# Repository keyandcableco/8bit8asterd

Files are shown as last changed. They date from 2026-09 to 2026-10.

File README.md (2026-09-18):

# 8b8 — 8-Bit 8asterd firmware

Arduino Leonardo driving three AY-3-8910A chips as a MIDI synth.

## Layout

- `8b8_firmware.ino` — the firmware
- `generate.py` — **single source of truth** for controllable parameters
- `parameters.h` — GENERATED. Do not edit by hand.
- `index.html` — GENERATED. Web Serial control panel (Chrome/Edge only).

## Workflow

Edit `PARAMS` / `PRESETS` in `generate.py`, then:

    python3 generate.py
    arduino-cli compile --fqbn arduino:avr:leonardo .
    arduino-cli upload -p /dev/ttyACM0 --fqbn arduino:avr:leonardo .

`generate.py` hashes the parameter definition into a layout-version byte.
When that byte changes the firmware ignores any saved EEPROM bank and boots
on defaults, so stale saves can never be misread as the new layout.

Open `index.html` directly in Chrome/Edge to control the unit. Close the tab
before flashing or the upload will fail on a busy serial port.

## Constraints

Leonardo (ATmega32u4): 28,672 bytes flash, 2,560 bytes RAM. RAM is the tight
one — keep constant tables in PROGMEM and read them with `pgm_read_*`.

Struct definitions must stay above the first function definition in the
.ino: the Arduino preprocessor inserts generated prototypes there, and a
type declared later breaks the build.

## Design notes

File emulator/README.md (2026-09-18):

# 8b8 emulator

Runs **the actual firmware** in a browser against three emulated AY-3-8910s.
`host.cpp` includes `8b8_firmware.ino` as a single translation unit, exactly
as the Arduino IDE builds it, so there is no second implementation to drift
out of step with the hardware.

The firmware needed one four-line change for this: an `AY_EMULATOR` seam in
`writeReg()` that hands register writes to the emulated chips instead of
bit-banging pins. It compiles to nothing on AVR.

## What's here

    arduino_shim.h   pins, PROGMEM, timers, EEPROM, Serial -- host stand-ins
    MIDIUSB.h        stub; the page injects note events into its queue
    MIDI.h           stub; DIN MIDI has no meaning in a browser
    ay8910.h         the chip: 3 tone channels, LFSR noise, envelope, log DAC
    host.cpp         drives setup()/loop(), renders audio, exposes the API
    emulator.html    GENERATED by ../generate.py -- same panel as index.html
    build-native.sh  g++ build for the tests
    build-wasm.sh    emcc build for the browser

## Build and run

    ./build-wasm.sh          # once emsdk is on your PATH
    python3 -m http.server 9111
    # open http://localhost:9111/emulator.html

Press **Start Audio**, then play with the letter keys (top rows pitched,
bottom row drums) or a MIDI keyboard.

## Tests

    ./build-native.sh && /tmp/8b8emu /tmp/out.wav

Renders a chord and a drum pattern to a WAV. `temper_test.cpp` reads the tone
periods the firmware programs and checks the temperaments land where they
should.

## Fidelity

The chip model steps at clock/8. The datasheet's tone frequency is
clock/(16*period) and the output toggles once per period, so a full square
cycle is two periods. Noise shifts every `2*period` steps and the envelope
advances every `32*period`, matching clock/(16*NP) and clock/(256*EP). The
DAC is the chip's logarithmic one, about 3dB per step.

Output is high-passed at about 3.5Hz to model the coupling capacitor on a
real board, so a muted channel's DC level does not appear as offset.

Not modelled: analogue output stage, supply noise, chip-to-chip variation,
and the exact bus timing (register writes go through the seam rather than
being decoded off BDIR/BC2).

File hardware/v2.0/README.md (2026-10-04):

# 8b8 hardware v2.0

RP2040 board for three YM2149 / AY-3-8910 sound chips, with eight analog
and eight switch inputs on terminal blocks. Everything except the sound chips
and the through-hole connectors is SMD with an LCSC part number, so JLC can
assemble it.

| File | What it is |
|---|---|
| `8b8_v2.kicad_pro`, `.kicad_sch`, `.kicad_pcb` | KiCad 9 project |
| `tools/design.py` | **The netlist, as data.** Every part, footprint, LCSC number and net. |
| `tools/gen_sch.py` | Writes the schematic from `design.py` |
| `tools/gen_pcb.py` | Writes the unrouted board: placement, outline, planes, silkscreen |
| `tools/route.py` | Autoroutes with Freerouting, then adds the copper pours |
| `tools/fixroute.py` | Small A* router for connections the autorouter left open |
| `tools/stitch.py` | Ground vias: beside stranded pads, a 4 mm grid, and inside walled-in pockets |
| `tools/cleanup.py` | Removes dangling track leftovers |
| `tools/check_netlist.py` | Checks that the schematic KiCad reads back matches `design.py` |
| `tools/check_pcb.py` | Checks every pad's net against the schematic, then runs DRC |
| `tools/fab.py` | Writes the JLC package into `fab/` |
| `fab/` | Gerbers (zip), BOM, CPL, and the list of through-hole parts |
| `renders/` | 3D views of the board |

## Status

Checked on the board as committed:

- **Schematic:** KiCad reads back the same 111 nets as `design.py`, with 0 mismatches.
  ERC shows 8 warnings, all one intended thing: the three chips' analog outputs
  are summed, as on v1.0. It's downgraded from error to warning in the project file.
- **Board:** 110 x 90 mm, 4 layers. **DRC: 0 errors, 0 unconnected, 0 schematic
  parity issues.** Every pad carries the right net. 6 cosmetic silkscreen
  warnings remain (a few labels touching vias); JLC clips silk off copper.
- **Stackup:** F.Cu signals, In1 solid GND, In2 signals plus +5V / +3V3 pours,
  B.Cu signals plus GND pour, ~350 stitching vias.
- **Rules:** 0.2 mm tracks, 0.15 mm clearance, 0.25 mm power, 0.6 / 0.3 mm vias.
  All standard JLC 4-layer capability.

### Before ordering

1. **Open it in KiCad and look.** It's autorouted. It's electrically complete
   and DRC-clean, but nobody has eyeballed it yet. Check the RP2040 and crystal
   area in particular, and tidy anything that looks odd.
2. **Check part rotations in JLC's CPL preview.** KiCad and JLC disagree on the
   zero rotation of some footprints (SOT-23, SOIC, the USB-C). JLC shows a
   preview after upload. Rotate any part whose pin 1 sits in the wrong corner.
3. **Through-hole parts** (sockets, terminal blocks) are in `fab/hand_solder.txt`.
   Add them as JLC through-hole assembly, or solder them yourself.
4. **Extended parts:** most ICs are JLC "Extended" library parts, so expect the
   per-part setup fee on top of the parts cost.

## Rebuilding

```bash
cd hardware/v2.0/tools
python3 gen_sch.py && python3 check_netlist.py
/usr/bin/python3 gen_pcb.py                        # needs KiCad's pcbnew module
DISPLAY=:0 /usr/bin/python3 route.py /path/to/freerouting-1.9.0.jar 15
DISPLAY=:0 /usr/bin/python3 route.py /path/to/freerouting-1.9.0.jar 8   # second pass
/usr/bin/python3 fixroute.py && /usr/bin/python3 stitch.py && /usr/bin/python3 stitch.py --islands
/usr/bin/python3 cleanup.py && /usr/bin/python3 check_pcb.py
/usr/bin/python3 fab.py
```

Freerouting 1.9 needs a display; it shows a window while it works. Autorouting
isn't deterministic, so a rebuild won't produce exactly this board. The last
few connections on this one were finished with a rip-up and reroute around
three debounce caps.

`gen_pcb.py` overwrites the board. **Now that it's routed, edit the layout by
hand in KiCad** and use *Update PCB from Schematic* for any circuit change. The
footprints are linked to the schematic symbols, so that works.

## What changed from v1

| | v1.0 (Pro Micro) | v2.0 |
|---|---|---|
| MCU | Pro Micro module on headers (ATmega32U4) | RP2040 on the board, 4 MB QSPI flash, 12 MHz crystal |
| Programming | Arduino bootloader | Hold BOOT, plug in USB, copy a `.uf2`. No programmer needed. |
| Logic to the chips | 5V straight from the 32U4 | Two 74HCT245 buffers (3.3V in, 5V out) |
| Warp Zone bends | A, B, X, Y (data bits DA1, DA0, DA5, DA4) on J3 | **Removed.** The firmware's Warp Zone does this safely. |
| CLK / RESET on J3 | `/SEL` (the half-clock bend) and `/RESET` | **Removed.** Clock Warp does the clock; reset is internal. |
| Inputs | none | 8 analog (74HC4051 to ADC0), 8 switch (74HC165) |
| Power | USB via Pro Micro | USB-C, 0.75 A polyfuse, AP2112K 3.3 V regulator |
| Audio out | 1k / 47n / 1u / 100k network | Same network, same values |
| MIDI in | 6N137, 220R, 1N4148 | Same circuit; output pulled up to 3.3 V |

## RP2040 pin map (for the firmware port)

| GPIO | Signal | Notes |
|---|---|---|
| 0-7 | DA0-DA7 | Data bus via U5. One masked write: `gpio_put_masked(0xFF, b)` |
| 8, 9 | BDIR_A, BC2_A | Chip A control via U6 |
| 10, 11 | BDIR_B, BC2_B | Chip B |
| 12, 13 | BDIR_C, BC2_C | Chip C |
| 14 | /RESET | All three chips. Pulled low until firmware drives it. |
| 15 | LED MIDI | Active high |
| 16 | spare | Test pad (UART0 TX, so a future MIDI out) |
| 17 | MIDI RX | UART0 RX, 31250 baud |
| 18, 19, 20 | MUX S0, S1, S2 | 74HC4051 channel select |
| 21 | CLOCK | GPOUT0. `clk_sys / 125` at 125 MHz gives exactly 1 MHz. Through U6, then 75R, then pin 22 of each chip. |
| 22, 23, 24 | SR /PL, CP, Q7 | 74HC165 |
| 25 | LED STATUS | Active high |
| 26 | MUX Z | ADC0 |
| 27, 28, 29 | spare | Test pads; ADC1-3 |

BC1 is grounded on every chip, the same reduced scheme as v1, so the
register-write sequence is unchanged.

Inside U5 and U6, channel *k* carries bit 7−*k*. That makes the bus run
straight from the RP2040 to the chips without crossing. It doesn't affect the
firmware: GPIO*n* still drives DA*n*.

### Reading the inputs

- **Analog:** set S2..S0 to the channel, wait about 10 µs, then read ADC0.
  Each input has 1k series and 10nF to ground. Pot ends go to the terminal's
  3V3 and GND pins, so the reading is ratiometric.
- **Switches:** pulse /PL low to latch, then clock out 8 bits on CP and read Q7.
  D0 (switch 1) comes out first. Inputs are active low: closed = 0. Each has
  a 10k pull-up and 1k/100nF debounce.

## Open questions

1. **v1.0 C2 is labelled "47uF" but drawn as a 5 mm disc ceramic.** v2.0 uses
   47 nF (3.4 kHz low-pass with the 1k). If your built v1 boards really have
   47 µF there, change it in `design.py`.
2. **v1.0 MIDI terminal labels.** v1's J3 labels the opto-cathode side "MIDI 4"
   and the 220R side "MIDI 5". The MIDI spec has DIN pin 4 on the resistor side,
   so v2.0 labels it that way. The circuit is identical; only the silkscreen
   differs.
3. **/A9, A8 and /SEL are left open, as on v1.0.** The chips pull them to the
   normal state. Tie them explicitly if you prefer.

## License

Copyright © 2026 Greg Miller / The Key & Cable Company.

The v2 hardware design files are licensed under the [CERN Open Hardware Licence Version 2 – Strongly Reciprocal (CERN-OHL-S-2.0)](../../LICENSE-HARDWARE). You can make, modify, sell and share hardware from them. If you share a modified design, or ship hardware made from one, you have to publish your design files under the same licence. The firmware is GPL-3.0 (see [LICENSE](../../LICENSE)).

Source location: <https://github.com/keyandcableco/8bit8asterd>

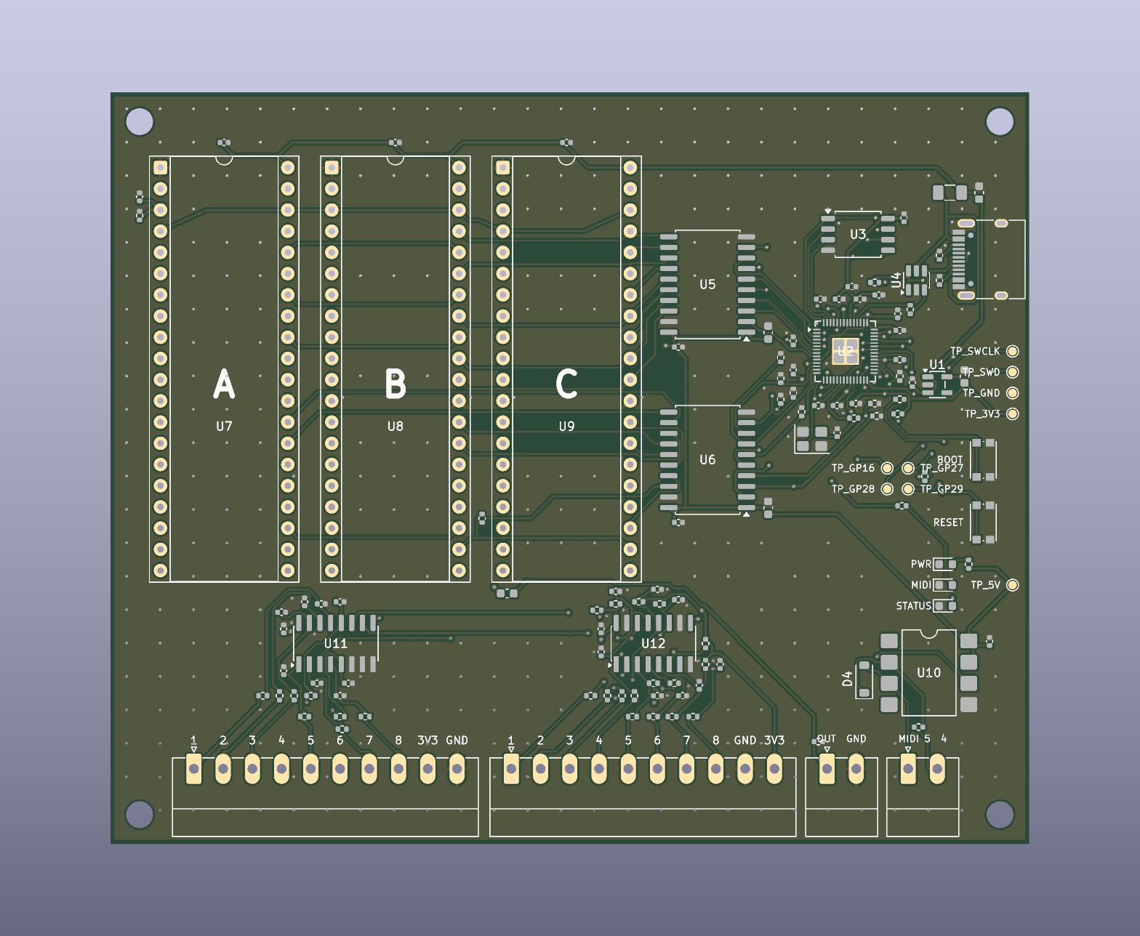
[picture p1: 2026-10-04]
hardware/v2.0/renders/8b8_v2_top.png

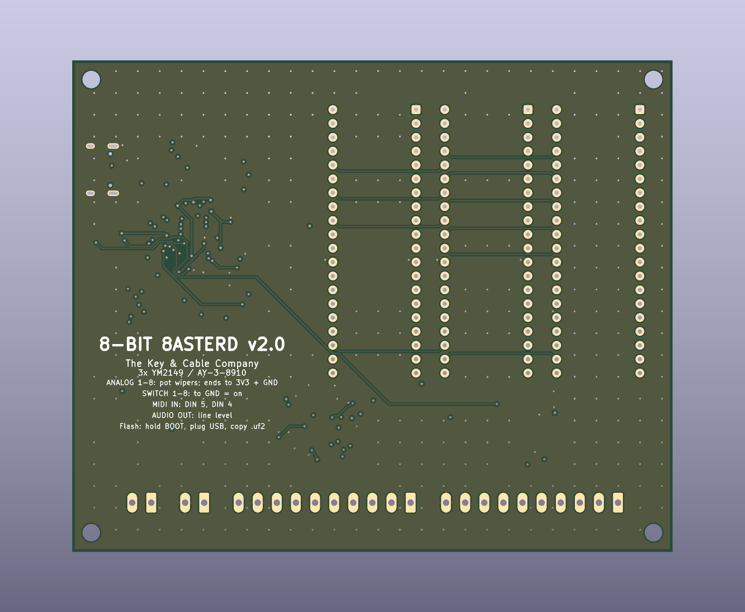
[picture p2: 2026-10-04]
hardware/v2.0/renders/8b8_v2_bottom.png

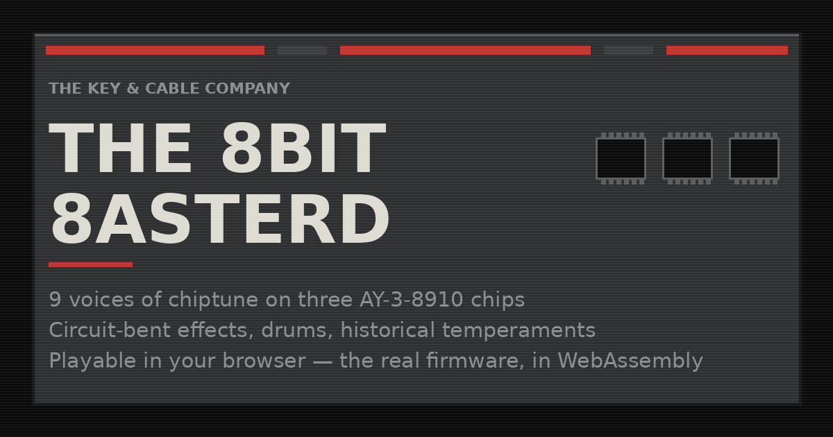
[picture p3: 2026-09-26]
emulator/social.png

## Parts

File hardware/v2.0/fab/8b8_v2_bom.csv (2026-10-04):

Comment | Designator | Footprint | LCSC Part #
10uF | C1,C2,C3 | C_0603_1608Metric | C96446
15pF | C18,C19 | C_0402_1005Metric | C1548
47nF | C26 | C_0402_1005Metric | C272875
1uF | C27 | C_0603_1608Metric | C106248
10nF | C30,C31,C32,C33,C34,C35,C36,C37 | C_0402_1005Metric | C15195
1uF | C4,C16,C17 | C_0402_1005Metric | C52923
10uF | C5 | C_0603_1608Metric | C19702
100nF | C6,C7,C8,C9,C10,C11,C12,C13,C14,C15,C20,C21,C22,C23,C24,C25,C28,C29,C38,C39,C40,C41,C42,C43,C44,C45,C46 | C_0402_1005Metric | C1525
PWR | D1 | LED_0603_1608Metric | C12624
MIDI | D2 | LED_0603_1608Metric | C12624
STATUS | D3 | LED_0603_1608Metric | C2286
1N4148W | D4 | D_SOD-123 | C81598
0.75A | F1 | Fuse_1206_3216Metric | C70078
USB-C | J1 | USB_C_Receptacle_HRO_TYPE-C-31-M-12 | C165948
5.1k | R1,R2 | R_0402_1005Metric | C25905
100k | R10,R11,R12,R13,R14,R15,R16,R17,R20 | R_0402_1005Metric | C25741
75 | R18 | R_0402_1005Metric | C25133
220 | R21 | R_0402_1005Metric | C25091
10k | R22,R32,R34,R36,R38,R40,R42,R44,R46 | R_0402_1005Metric | C25744
1k | R3,R4,R5,R8,R9,R19,R23,R24,R25,R26,R27,R28,R29,R30,R31,R33,R35,R37,R39,R41,R43,R45 | R_0402_1005Metric | C11702
27 | R6,R7 | R_0402_1005Metric | C25156
BOOT | SW1 | SW_Push_1P1T_NO_CK_KMR2 | C318884
RESET | SW2 | SW_Push_1P1T_NO_CK_KMR2 | C318884
AP2112K-3.3 | U1 | SOT-23-5 | C51118
6N137S | U10 | SMDIP-8_W9.53mm | C16496
74HC4051 | U11 | SOIC-16_3.9x9.9mm_P1.27mm | C9386
74HC165 | U12 | SOIC-16_3.9x9.9mm_P1.27mm | C5613
RP2040 | U2 | QFN-56-1EP_7x7mm_P0.4mm_EP3.2x3.2mm | C2040
W25Q32JVSSIQ | U3 | SOIC-8_5.3x5.3mm_P1.27mm | C179173
USBLC6-2SC6 | U4 | SOT-23-6 | C7519
74HCT245 | U5,U6 | SOIC-20W_7.5x12.8mm_P1.27mm | C5979
12MHz | Y1 | Crystal_SMD_3225-4Pin_3.2x2.5mm | C9002

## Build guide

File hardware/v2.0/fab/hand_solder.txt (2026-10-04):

Through-hole parts, not in the SMT assembly files.
Add them to the JLC order as through-hole assembly, or solder by hand.

U7    YM2149 / AY-3-8910   DIP-40_W15.24mm_Socket                                     LCSC C2332
U8    YM2149 / AY-3-8910   DIP-40_W15.24mm_Socket                                     LCSC C2332
U9    YM2149 / AY-3-8910   DIP-40_W15.24mm_Socket                                     LCSC C2332
J2    AUDIO OUT            PhoenixContact_MC_1,5_2-G-3.5_1x02_P3.50mm_Horizontal      LCSC C395830
J3    MIDI IN              PhoenixContact_MC_1,5_2-G-3.5_1x02_P3.50mm_Horizontal      LCSC C395830
J4    ANALOG IN            PhoenixContact_MC_1,5_10-G-3.5_1x10_P3.50mm_Horizontal     LCSC C430562
J5    SWITCH IN            PhoenixContact_MC_1,5_10-G-3.5_1x10_P3.50mm_Horizontal     LCSC C430562

Plus your three YM2149 / AY-3-8910 chips in U7, U8, U9 (pin 1 at the square pad).
The terminal blocks are pluggable headers: buy matching 3.5 mm plugs
(DORABO DB2EK-3.5-10P-GN-S, LCSC C395846, x2; DB2EK-3.5-2P-GN-S,
LCSC C395828, x2) for the wires.

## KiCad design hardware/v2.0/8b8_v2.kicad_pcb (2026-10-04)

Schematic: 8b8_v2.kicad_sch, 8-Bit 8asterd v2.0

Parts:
C1, C2, C3: 10uF; C_0603_1608Metric; LCSC C96446
C4, C16, C17: 1uF; C_0402_1005Metric; LCSC C52923
C5: 10uF; C_0603_1608Metric; LCSC C19702
C6, C7, C8, C9, C10, C11, C12, C13, C14, C15, C20, C21, C22, C23, C24, C25, C28, C29, C38, C39, C40, C41, C42, C43, C44, C45, C46: 100nF; C_0402_1005Metric; LCSC C1525
C18, C19: 15pF; C_0402_1005Metric; LCSC C1548
C26: 47nF; C_0402_1005Metric; LCSC C272875
C27: 1uF; C_0603_1608Metric; LCSC C106248
C30, C31, C32, C33, C34, C35, C36, C37: 10nF; C_0402_1005Metric; LCSC C15195
D1: PWR; LED_0603_1608Metric; LCSC C12624
D2: MIDI; LED_0603_1608Metric; LCSC C12624
D3: STATUS; LED_0603_1608Metric; LCSC C2286
D4: 1N4148W; D_SOD-123; LCSC C81598
F1: 0.75A; Fuse_1206_3216Metric; LCSC C70078
H1, H2, H3, H4: M3; MountingHole_3.2mm_M3
J1: USB-C; USB_C_Receptacle_HRO_TYPE-C-31-M-12; LCSC C165948
J2: AUDIO OUT; PhoenixContact_MC_1,5_2-G-3.5_1x02_P3.50mm_Horizontal; LCSC C395830
J3: MIDI IN; PhoenixContact_MC_1,5_2-G-3.5_1x02_P3.50mm_Horizontal; LCSC C395830
J4: ANALOG IN; PhoenixContact_MC_1,5_10-G-3.5_1x10_P3.50mm_Horizontal; LCSC C430562
J5: SWITCH IN; PhoenixContact_MC_1,5_10-G-3.5_1x10_P3.50mm_Horizontal; LCSC C430562
R1, R2: 5.1k; R_0402_1005Metric; LCSC C25905
R3, R4, R5, R8, R9, R19, R23, R24, R25, R26, R27, R28, R29, R30, R31, R33, R35, R37, R39, R41, R43, R45: 1k; R_0402_1005Metric; LCSC C11702
R6, R7: 27; R_0402_1005Metric; LCSC C25156
R10, R11, R12, R13, R14, R15, R16, R17, R20: 100k; R_0402_1005Metric; LCSC C25741
R18: 75; R_0402_1005Metric; LCSC C25133
R21: 220; R_0402_1005Metric; LCSC C25091
R22, R32, R34, R36, R38, R40, R42, R44, R46: 10k; R_0402_1005Metric; LCSC C25744
SW1: BOOT; SW_Push_1P1T_NO_CK_KMR2; LCSC C318884
SW2: RESET; SW_Push_1P1T_NO_CK_KMR2; LCSC C318884
TP_3V3: TP_3V3; TestPoint_Pad_D1.0mm
TP_5V: TP_5V; TestPoint_Pad_D1.0mm
TP_GND: TP_GND; TestPoint_Pad_D1.0mm
TP_GP16: TP_GP16; TestPoint_Pad_D1.0mm
TP_GP27: TP_GP27; TestPoint_Pad_D1.0mm
TP_GP28: TP_GP28; TestPoint_Pad_D1.0mm
TP_GP29: TP_GP29; TestPoint_Pad_D1.0mm
TP_SWCLK: TP_SWCLK; TestPoint_Pad_D1.0mm
TP_SWD: TP_SWD; TestPoint_Pad_D1.0mm
U1: AP2112K-3.3; SOT-23-5; LCSC C51118
U2: RP2040; QFN-56-1EP_7x7mm_P0.4mm_EP3.2x3.2mm; LCSC C2040
U3: W25Q32JVSSIQ; SOIC-8_5.3x5.3mm_P1.27mm; LCSC C179173
U4: USBLC6-2SC6; SOT-23-6; LCSC C7519
U5, U6: 74HCT245; SOIC-20W_7.5x12.8mm_P1.27mm; LCSC C5979
U7, U8, U9: YM2149 / AY-3-8910; DIP-40_W15.24mm_Socket; LCSC C2332
U10: 6N137S; SMDIP-8_W9.53mm; LCSC C16496
U11: 74HC4051; SOIC-16_3.9x9.9mm_P1.27mm; LCSC C9386
U12: 74HC165; SOIC-16_3.9x9.9mm_P1.27mm; LCSC C5613
Y1: 12MHz; Crystal_SMD_3225-4Pin_3.2x2.5mm; LCSC C9002

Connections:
+1V1: C14.1, C15.1, C17.1, U2.23 (DVDD), U2.45 (VREG_VOUT), U2.50 (DVDD)
+3V3: C5.1, C6.1, C7.1, C8.1, C9.1, C10.1, C11.1, C12.1, C13.1, C16.1, C20.1, C29.1, C38.1, J4.9, J5.10, R22.2, R32.2, R34.2, R36.2, R38.2, R40.2, R42.2, R44.2, R46.2, TP_3V3.1, U1.5 (VOUT), U2.1 (IOVDD), U2.10 (IOVDD), U2.22 (IOVDD), U2.33 (IOVDD), U2.42 (IOVDD), U2.43 (ADC_AVDD), U2.44 (VREG_VIN), U2.48 (USB_VDD), U2.49 (IOVDD), U3.8 (VCC), U11.16 (VCC), U12.16 (VCC)
+5V: C1.1, C2.1, C3.1, C4.1, C21.1, C22.1, C23.1, C24.1, C25.1, C28.1, F1.2, R3.1, TP_5V.1, U1.1 (VIN), U1.3 (EN), U5.1 (A->B), U5.20 (VCC), U6.1 (A->B), U6.20 (VCC), U7.40 (VCC), U8.40 (VCC), U9.40 (VCC), U10.7 (EN), U10.8 (VCC)
/AUDIO: C26.1, C27.1, R19.1, U7.3 (A), U7.4 (B), U7.38 (C), U8.3 (A), U8.4 (B), U8.38 (C), U9.3 (A), U9.4 (B), U9.38 (C)
/AUDIO_OUT: C27.2, J2.1, R20.1
/AY_CLK: R18.2, U7.22 (CLOCK), U8.22 (CLOCK), U9.22 (CLOCK)
/AY_RESET: U6.17 (B1), U7.23 (~RESET), U8.23 (~RESET), U9.23 (~RESET)
/BC2_A: U6.12 (B6), U7.28 (BC2)
/BC2_A_MCU: R11.1, U2.12 (GPIO9), U6.8 (A6)
/BC2_B: U6.14 (B4), U8.28 (BC2)
/BC2_B_MCU: R13.1, U2.14 (GPIO11), U6.6 (A4)
/BC2_C: U6.16 (B2), U9.28 (BC2)
/BC2_C_MCU: R15.1, U2.16 (GPIO13), U6.4 (A2)
/BDIR_A: U6.11 (B7), U7.27 (BDIR)
/BDIR_A_MCU: R10.1, U2.11 (GPIO8), U6.9 (A7)
/BDIR_B: U6.13 (B5), U8.27 (BDIR)
/BDIR_B_MCU: R12.1, U2.13 (GPIO10), U6.7 (A5)
/BDIR_C: U6.15 (B3), U9.27 (BDIR)
/BDIR_C_MCU: R14.1, U2.15 (GPIO12), U6.5 (A3)
/BOOTSEL: R5.2, SW1.1
/CC1: J1.A5 (CC1), R1.1
/CC2: J1.B5 (CC2), R2.1
/CLK_BUF: R18.1, U6.18 (B0)
/CLK_MCU: R17.1, U2.32 (GPIO21), U6.2 (A0)
/D0_MCU: U2.2 (GPIO0), U5.9 (A7)
/D1_MCU: U2.3 (GPIO1), U5.8 (A6)
/D2_MCU: U2.4 (GPIO2), U5.7 (A5)
/D3_MCU: U2.5 (GPIO3), U5.6 (A4)
/D4_MCU: U2.6 (GPIO4), U5.5 (A3)
/D5_MCU: U2.7 (GPIO5), U5.4 (A2)
/D6_MCU: U2.8 (GPIO6), U5.3 (A1)
/D7_MCU: U2.9 (GPIO7), U5.2 (A0)
/DA0: U5.11 (B7), U7.37 (DA0), U8.37 (DA0), U9.37 (DA0)
/DA1: U5.12 (B6), U7.36 (DA1), U8.36 (DA1), U9.36 (DA1)
/DA2: U5.13 (B5), U7.35 (DA2), U8.35 (DA2), U9.35 (DA2)
/DA3: U5.14 (B4), U7.34 (DA3), U8.34 (DA3), U9.34 (DA3)
/DA4: U5.15 (B3), U7.33 (DA4), U8.33 (DA4), U9.33 (DA4)
/DA5: U5.16 (B2), U7.32 (DA5), U8.32 (DA5), U9.32 (DA5)
/DA6: U5.17 (B1), U7.31 (DA6), U8.31 (DA6), U9.31 (DA6)
/DA7: U5.18 (B0), U7.30 (DA7), U8.30 (DA7), U9.30 (DA7)
/GP16: TP_GP16.1, U2.27 (GPIO16)
/GP27: TP_GP27.1, U2.39 (GPIO27/ADC1)
/GP28: TP_GP28.1, U2.40 (GPIO28/ADC2)
/GP29: TP_GP29.1, U2.41 (GPIO29/ADC3)
/IN_A1: J4.1, R23.1
/IN_A2: J4.2, R24.1
/IN_A3: J4.3, R25.1
/IN_A4: J4.4, R26.1
/IN_A5: J4.5, R27.1
/IN_A6: J4.6, R28.1
/IN_A7: J4.7, R29.1
/IN_A8: J4.8, R30.1
/IN_D1: J5.1, R31.1
/IN_D2: J5.2, R33.1
/IN_D3: J5.3, R35.1
/IN_D4: J5.4, R37.1
/IN_D5: J5.5, R39.1
/IN_D6: J5.6, R41.1
/IN_D7: J5.7, R43.1
/IN_D8: J5.8, R45.1
/LED_MIDI_A: D2.2 (A), R8.2
/LED_MIDI_MCU: R8.1, U2.18 (GPIO15)
/LED_PWR_A: D1.2 (A), R3.2
/LED_STAT_A: D3.2 (A), R9.2
/LED_STAT_MCU: R9.1, U2.37 (GPIO25)
/MIDI_4: J3.2, R21.1
/MIDI_5: D4.2 (A), J3.1, U10.3 (C)
/MIDI_RX: R22.1, U2.28 (GPIO17), U10.6 (VO)
/MUX_S0: U2.29 (GPIO18), U11.11 (S0)
/MUX_S1: U2.30 (GPIO19), U11.10 (S1)
/MUX_S2: U2.31 (GPIO20), U11.9 (S2)
/MUX_Y0: C30.1, R23.2, U11.13 (A0)
/MUX_Y1: C31.1, R24.2, U11.14 (A1)
/MUX_Y2: C32.1, R25.2, U11.15 (A2)
/MUX_Y3: C33.1, R26.2, U11.12 (A3)
/MUX_Y4: C34.1, R27.2, U11.1 (A4)
/MUX_Y5: C35.1, R28.2, U11.5 (A5)
/MUX_Y6: C36.1, R29.2, U11.2 (A6)
/MUX_Y7: C37.1, R30.2, U11.4 (A7)
/MUX_Z: U2.38 (GPIO26/ADC0), U11.3 (A)
/OPTO_A: D4.1 (K), R21.2, U10.2 (A)
/QSPI_SCLK: U2.52 (QSPI_SCLK), U3.6 (CLK)
/QSPI_SD0: U2.53 (QSPI_SD0), U3.5 (DI/IO_{0})
/QSPI_SD1: U2.55 (QSPI_SD1), U3.2 (DO/IO_{1})
/QSPI_SD2: U2.54 (QSPI_SD2), U3.3 (~WP/IO_{2})
/QSPI_SD3: U2.51 (QSPI_SD3), U3.7 (~HOLD/~RESET/IO_{3})
/QSPI_SS: R5.1, U2.56 (~QSPI_SS), U3.1 (~CS)
/RESET_MCU: R16.1, U2.17 (GPIO14), U6.3 (A1)
/RUN: SW2.1, U2.26 (RUN)
/SR_CP: U2.35 (GPIO23), U12.2 (CP)
/SR_PL: U2.34 (GPIO22), U12.1 (~PL)
/SR_Q7: U2.36 (GPIO24), U12.9 (Q7)
/SWCLK: TP_SWCLK.1, U2.24 (SWCLK)
/SWD: TP_SWD.1, U2.25 (SWDIO)
/SW_D0: C39.1, R31.2, R32.1, U12.11 (D0)
/SW_D1: C40.1, R33.2, R34.1, U12.12 (D1)
/SW_D2: C41.1, R35.2, R36.1, U12.13 (D2)
/SW_D3: C42.1, R37.2, R38.1, U12.14 (D3)
/SW_D4: C43.1, R39.2, R40.1, U12.3 (D4)
/SW_D5: C44.1, R41.2, R42.1, U12.4 (D5)
/SW_D6: C45.1, R43.2, R44.1, U12.5 (D6)
/SW_D7: C46.1, R45.2, R46.1, U12.6 (D7)
/USB_DM: R7.2, U2.46 (USB_DM)
/USB_DM_C: J1.A7 (D-), J1.B7 (D-), R7.1, U4.3 (I/O2), U4.4 (I/O2)
/USB_DP: R6.2, U2.47 (USB_DP)
/USB_DP_C: J1.A6 (D+), J1.B6 (D+), R6.1, U4.1 (I/O1), U4.6 (I/O1)
/VBUS: F1.1, J1.A4 (VBUS), J1.A9 (VBUS), J1.B4 (VBUS), J1.B9 (VBUS), U4.5 (VBUS)
/XIN: C18.1, U2.20 (XIN), Y1.1
/XOUT_MCU: R4.1, U2.21 (XOUT)
/XOUT_X: C19.1, R4.2, Y1.3
GND: C1.2, C2.2, C3.2, C4.2, C5.2, C6.2, C7.2, C8.2, C9.2, C10.2, C11.2, C12.2, C13.2, C14.2, C15.2, C16.2, C17.2, C18.2, C19.2, C20.2, C21.2, C22.2, C23.2, C24.2, C25.2, C26.2, C28.2, C29.2, C30.2, C31.2, C32.2, C33.2, C34.2, C35.2, C36.2, C37.2, C38.2, C39.2, C40.2, C41.2, C42.2, C43.2, C44.2, C45.2, C46.2, D1.1 (K), D2.1 (K), D3.1 (K), J1.A1 (GND), J1.A12 (GND), J1.B1 (GND), J1.B12 (GND), J1.S1 (SHIELD), J2.2, J4.10, J5.9, R1.2, R2.2, R10.2, R11.2, R12.2, R13.2, R14.2, R15.2, R16.2, R17.2, R19.2, R20.2, SW1.2, SW2.2, TP_GND.1, U1.2 (GND), U2.19 (TESTEN), U2.57 (GND), U3.4 (GND), U4.2 (GND), U5.10 (GND), U5.19 (CE), U6.10 (GND), U6.19 (CE), U7.1 (VSS), U7.29 (BC1), U8.1 (VSS), U8.29 (BC1), U9.1 (VSS), U9.29 (BC1), U10.5 (GND), U11.6 (~E), U11.7 (VEE), U11.8 (GND), U12.8 (GND), U12.10 (DS), U12.15 (~CE), Y1.2 (G), Y1.4 (G)

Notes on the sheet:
POWER: USB-C -> fuse -> 5V -> 3.3V
RP2040 CORE
3.3V -> 5V LEVEL BUFFERS
THREE YM2149 / AY-3-8910 SOUND CHIPS
AUDIO OUT (same network as v1.0)
MIDI IN
INPUTS: 8 analog (74HC4051) + 8 digital (74HC165)
MECHANICAL

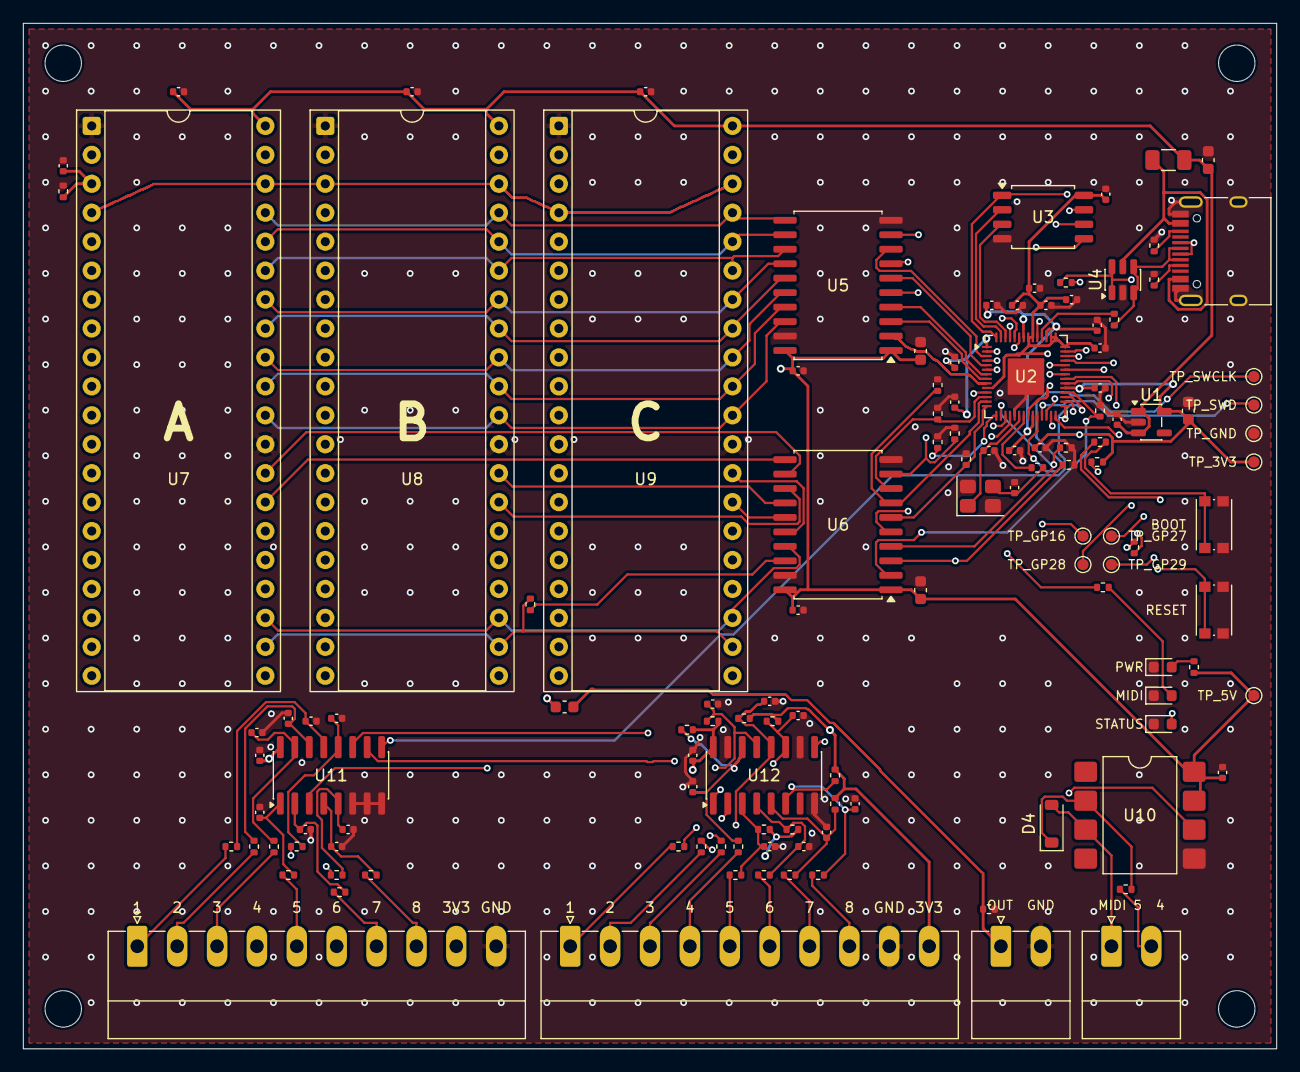
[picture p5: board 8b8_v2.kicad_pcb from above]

Board: 4 copper layers, 110.0 x 90.0 mm, 130 parts (0 on the bottom side), 111 nets.

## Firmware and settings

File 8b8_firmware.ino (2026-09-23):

// 8-Bit 8asterd -- a nine-voice MIDI chiptune synthesiser for three
// AY-3-8910 programmable sound generators driven by an Arduino Leonardo.
//
// Copyright (C) 2026 Greg Miller, The Key & Cable Company
//
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
// Derived from:
//   Arduino MIDI Chiptune Synthesizer by Ian Harvey (TheSpodShed)
//     https://www.instructables.com/Arduino-MIDI-Chiptune-Synthesizer/
//   Dual AY-3-8910 MIDI module by Doge Microsystems
//     https://dogemicrosystems.ca/wiki/Dual_AY-3-8910_MIDI_module
// The reduced BC1-grounded control scheme, the note table and the original
// voice-allocation approach come from that work.

/*
 * The bulk of this firmware comes from: https://dogemicrosystems.ca/wiki/Dual_AY-3-8910_MIDI_module
 * 
 * Firmware Version 2.2 for the 8-Bit 8asterd by Semiotic Sounds
 * 
 * Added:
 * Drum Polyphony
 * Slow attack evelopes on channels 3 and 4
 * Altered drum sounds (808 bass and clave)
 * Arduino Reset function on MIDI KillAll message
 * Better voice distribution methodology
 */

// resetFunc() removed: All Notes Off now calls softReset() instead of
// rebooting the MCU. See softReset() further down.

// Uncomment to enable 5-pin DIN serial midi
#define SERIALMIDI

// Uncomment to enable USB midi
#define USBMIDI

// Uncomment to enable debugging output over USB serial
#define DEBUG

#include <avr/io.h>
#include <string.h>
#include <stdlib.h>

#ifdef USBMIDI
#include "MIDIUSB.h"
#endif

// We borrow one struct from MIDIUSB for traditional serial midi, so define it if were not using USBMIDI
#ifndef MIDIUSB_h
typedef struct
{
  uint8_t header;
  uint8_t byte1;
  uint8_t byte2;
  uint8_t byte3;
} midiEventPacket_t;
#endif

#ifdef SERIALMIDI
#include <MIDI.h>
MIDI_CREATE_INSTANCE(HardwareSerial, Serial1, MIDI);//Serial1 on pro micro
#endif

typedef unsigned short int ushort;

typedef unsigned char note_t;
#define NOTE_OFF 0

typedef unsigned char midictrl_t;

// --- Fast direct-port I/O -------------------------------------------------
// KEEP THESE STRUCTS ABOVE EVERY FUNCTION DEFINITION IN THIS FILE. The
// Arduino .ino preprocessor auto-generates function prototypes and inserts
// them immediately before the first function definition; pinHigh()/pinLow()
// take a BusPin&, so if BusPin is declared after that point the generated
// prototype references an undeclared type and the build fails with
// "'BusPin' does not name a type".
//
// digitalWrite() costs ~50+ cycles on AVR (pin validation, PWM-timer
// disable check, interrupt mask save/restore). Every register write here
// needs 8 data-bit writes plus several BDIR/BC2 toggles, and this happens
// constantly on the voice/envelope hot path while MIDI also needs servicing.
// We resolve each pin to its AVR PORT register + bitmask once at startup
// (via the standard Arduino pin-mapping macros, so this stays portable if
// pins are reassigned) and then do a 1-2 instruction read-modify-write
// instead. This is roughly an order of magnitude faster per pin toggle.

struct BusPin {
  volatile uint8_t *port;
  uint8_t mask;
};

static BusPin dbusPins[8];

struct ChipCtl {
  BusPin bdir;
  BusPin bc2;
};

static ChipCtl chipCtl[3]; // 0 = chip A, 1 = chip B, 2 = chip C

// Voice/FX parameter structs live up here for the same reason as BusPin
// above: any top-level function taking one (applyDrumMods) gets an
// auto-generated prototype inserted before the first function definition.

struct FXParams {
  ushort noisefreq;
  ushort tonefreq;
  ushort envdecay;
  ushort freqdecay;
  ushort timer;
  ushort shape;
};

struct ToneParams {
  ushort attack;
  ushort decay;
  ushort sustain; // Values 0..32
  ushort rel;
};

// --- Parameter bank -------------------------------------------------------
// parameters.h is GENERATED by generate.py (indices, ranges, defaults, and a
// layout-version byte). The bank is a flat uint8_t array in index order --
// the same array the web panel edits over serial and that presets are made
// of. Edit generate.py, re-run it, reflash; never edit parameters.h by hand.
#include "parameters.h"
#include "temperaments.h"
#include <EEPROM.h>

static uint8_t params[NUM_PARAMS];

// MIDI CC control. Every parameter answers to a CC so the box can be driven
// from whatever controller someone already owns. Defaults are laid out from
// CC_BASE upward, in the 70-119 "sound controller / undefined" range, which
// avoids mod wheel, volume, sustain, the bank-select LSBs and the channel
// mode messages. Any of them can be re-learned to whatever a controller
// actually sends, and the map rides along in EEPROM with the parameters.
#define CC_BASE 70
#define CC_NONE 255
static uint8_t ccMap[NUM_PARAMS];
static uint8_t ccLearnTarget = CC_NONE;   // parameter awaiting the next CC

static void loadDefaultCcMap() {
  for (uint8_t i = 0; i < NUM_PARAMS; i++) {
    uint8_t cc = CC_BASE + i;
    ccMap[i] = (cc <= 119) ? cc : CC_NONE;   // past 119 there is no room left
  }
}

// AY envelope shapes that loop continuously (P_BUZZ_SHAPE is an index here):
static const uint8_t buzzShapes[4] PROGMEM = { 8, 10, 12, 14 };

static void loadDefaults() {
  for (uint8_t i = 0; i < NUM_PARAMS; i++) {
    params[i] = pgm_read_byte(&PARAM_DEFAULT[i]);
  }
}

static void setParam(uint8_t idx, int val) {
  if (idx >= NUM_PARAMS) return;
  int lo = pgm_read_byte(&PARAM_MIN[idx]);
  int hi = pgm_read_byte(&PARAM_MAX[idx]);
  if (val < lo) val = lo;
  if (val > hi) val = hi;
  params[idx] = (uint8_t)val;
}

// EEPROM layout: '8' 'B' <layout version> <param count> <params...>
// The layout version is derived from the parameter definition by
// generate.py, so a saved bank from an older definition is simply ignored.
static void saveParamsToEEPROM() {
  EEPROM.update(0, '8');
  EEPROM.update(1, 'B');
  EEPROM.update(2, PARAM_LAYOUT_VERSION);
  EEPROM.update(3, NUM_PARAMS);
  for (uint8_t i = 0; i < NUM_PARAMS; i++) {
    EEPROM.update(4 + i, params[i]);
    EEPROM.update(4 + NUM_PARAMS + i, ccMap[i]);
  }
}

static bool loadParamsFromEEPROM() {
  if (EEPROM.read(0) != '8' || EEPROM.read(1) != 'B' ||
      EEPROM.read(2) != PARAM_LAYOUT_VERSION || EEPROM.read(3) != NUM_PARAMS) {
    return false;
  }
  for (uint8_t i = 0; i < NUM_PARAMS; i++) {
    setParam(i, EEPROM.read(4 + i)); // clamp on the way in
    uint8_t cc = EEPROM.read(4 + NUM_PARAMS + i);
    ccMap[i] = (cc <= 119 || cc == CC_NONE) ? cc : CC_NONE;
  }
  return true;
}

// Pin driver ---------------------------------------------

// Pin numbers all fit in a byte; PROGMEM keeps the table out of RAM.
static const uint8_t dbus[8] PROGMEM = { 2, 3, 4, 5, 6, 7, 8, 10 };

static const ushort
  BC2_A = 14,
  BDIR_A = 16,
  BC2_B = A1,
  BDIR_B = A0,
  BC2_C = A3,
  BDIR_C = A2,
  nRESET = 15,
  clkOUT = 9;

static const ushort DIVISOR = 7; // Set for 1MHz clock


static void clockSetup() {
   // Timer 1 setup for Mega32U4 devices
   //
   // Use CTC mode: WGM13..0 = 0100
   // Toggle OC1A on Compare Match: COM1A1..0 = 01
   // Use ClkIO with no prescaling: CS12..0 = 001
   // Interrupts off: TIMSK0 = 0
   // OCR0A = interval value
   
   TCCR1A = (1 << COM1A0);
   TCCR1B = (1 << WGM12) | (1 << CS10);
   TCCR1C = 0;
   TIMSK1 = 0;
   OCR1AH = 0;
   OCR1AL = DIVISOR; // NB write high byte first
}


static inline void pinHigh(const BusPin &p) { *p.port |= p.mask; }
static inline void pinLow(const BusPin &p)  { *p.port &= ~p.mask; }

static void setData(unsigned char db) {
  unsigned char bit = 1;
  for (ushort i = 0; i < 8; i++) {
    if (db & bit) pinHigh(dbusPins[i]);
    else pinLow(dbusPins[i]);
    bit <<= 1;
  }
}

static void initBusPins() {
  for (uint8_t i = 0; i < 8; i++) {
    uint8_t pin = pgm_read_byte(&dbus[i]);
    dbusPins[i].port = portOutputRegister(digitalPinToPort(pin));
    dbusPins[i].mask = digitalPinToBitMask(pin);
  }

  const ushort bdirPins[3] = { BDIR_A, BDIR_B, BDIR_C };
  const ushort bc2Pins[3]  = { BC2_A,  BC2_B,  BC2_C  };

  for (uint8_t c = 0; c < 3; c++) {
    chipCtl[c].bdir.port = portOutputRegister(digitalPinToPort(bdirPins[c]));
    chipCtl[c].bdir.mask = digitalPinToBitMask(bdirPins[c]);
    chipCtl[c].bc2.port  = portOutputRegister(digitalPinToPort(bc2Pins[c]));
    chipCtl[c].bc2.mask  = digitalPinToBitMask(bc2Pins[c]);
  }
}

#ifdef AY_EMULATOR
// Emulator seam. The browser build runs this exact firmware, so register
// writes are handed to the emulated chips instead of being bit-banged onto
// real pins. Costs nothing on AVR: the macro is not defined there.
extern void emuWriteReg(uint8_t chip, unsigned char reg, unsigned char db);
#endif

static void writeReg(uint8_t chip, unsigned char reg, unsigned char db) {
#ifdef AY_EMULATOR
  emuWriteReg(chip, reg, db);
  return;
#endif
  // Same BC1-kept-low NACT/BAR/IAB/DWS sequencing as the original, just
  // routed through direct port writes instead of digitalWrite().
  //
  // ATOMIC: an interrupt landing between the address latch and the data
  // write would corrupt the transfer. Nothing writes registers from an ISR
  // today, but the cost is a few cycles and it keeps the bus safe if
  // anything ever does again.
  uint8_t sreg_save = SREG;
  cli();
  ChipCtl &c = chipCtl[chip];

  // Inactive (BDIR BC2 BC1 0 0 0)
  pinLow(c.bdir);
  pinLow(c.bc2);

  // Set register address
  setData(reg);

  // BAR (Latch) (BDIR BC2 BC1 1 0 0)
  pinHigh(c.bdir);

  // Inactive (BDIR BC2 BC1 0 0 0)
  pinLow(c.bdir);

  // Set register contents
  setData(db);

  // Write (BDIR BC2 BC1 1 1 0)
  pinHigh(c.bc2);
  pinHigh(c.bdir);

  // Inactive (BDIR BC2 BC1 0 0 0)
  pinLow(c.bc2);
  pinLow(c.bdir);

  SREG = sreg_save;
}

// AY-3-8910 driver ---------------------------------------

class PSGRegs {
public:
  enum {
    TONEALOW = 0,
    TONEAHIGH,
    TONEBLOW,
    TONEBHIGH,
    TONECLOW,
    TONECHIGH,
    NOISEGEN,
    MIXER,
    TONEAAMPL,
    TONEBAMPL,
    TONECAMPL,
    ENVLOW,
    ENVHIGH,
    ENVSHAPE,
    IOA,
    IOB
  };

  //MIXER
//   0 = A+B+C+Noise            [0]
// 248 = A+B+C                  [1]
// 199 = Noise only on A+B+C    [2]
// 254 = A Only                 [3]
// 253 = B only                 [4]
// 251 = C only                 [5]
// 252 = A+B                    [6]
// 249 = B+C                    [7]
// 246 = A+Noise                [8]
// 237 = B+Noise                [9]
// 219 = C+Noise                [10]
// 238 = A+Noise on B           [11]
// 221 = B+Noise on C           [12]
// 243 = C+Noise on A           [13]
// 247 = Noise only on A        [14]
// 239 = Noise only on B        [15]
// 223 = Noise only on C        [16]
  
  // Chip-indexed register storage: regs[0]=chip A, regs[1]=chip B, regs[2]=chip C.
  // The original had three full copies of these arrays (regs_A/B/C,
  // lastregs_A/B/C) plus three near-identical writeReg_A/B/C and three
  // near-identical update_A/B/C. Every voice channel 0..8 maps onto one of
  // the three chips via chip = ch % 3 and a sub-channel sub = ch / 3 (0,3,6
  // -> chip A; 1,4,7 -> chip B; 2,5,8 -> chip C, matching the original
  // mapping exactly). That collapses what used to be three copy-pasted
  // if/else-if chains per method into one formula, and incidentally fixes a
  // real bug in the original setPercOff(): its chip-A branch read
  // regs_C[MIXER] and its chip-C branch read regs_A[MIXER] instead of their
  // own chip's mixer register.
  unsigned char regs[3][16];
  unsigned char lastregs[3][16];

  void init() {
    for (uint8_t c = 0; c < 3; c++) {
      for (int i = 0; i < 16; i++) {
        regs[c][i] = lastregs[c][i] = 0xFF;
        writeReg(c, i, regs[c][i]);
      }
    }
  }

  void update(uint8_t chip) {
    unsigned char *r = regs[chip];
    unsigned char *lr = lastregs[chip];
    for (int i = 0; i < 16; i++) {
      if (r[i] != lr[i]) {
        writeReg(chip, i, r[i]);
        lr[i] = r[i];
      }
    }
  }

  void updateAll() {
    update(0);
    update(1);
    update(2);
  }

  void setTone(ushort ch, ushort divisor, ushort ampl) {
    uint8_t chip = ch % 3;
    uint8_t sub  = ch / 3;
    unsigned char *r = regs[chip];

    r[TONEALOW  + (sub<<1)] = (divisor & 0xFF);
    r[TONEAHIGH + (sub<<1)] = (divisor >> 8);
    r[TONEAAMPL + sub] = ampl;

    ushort mask = (8+1) << sub;
    r[MIXER] = (r[MIXER] | mask) ^ (1 << sub);
  }

  // keepNoise leaves the chip's noise period as it is. The generator is one
  // per chip, so writing it changes the colour of any noise drum already
  // decaying there: a hat at period 0 landing on a ringing snare at 6 turns
  // the snare's hiss bright halfway through. The arriving hit takes the
  // period that is there instead, which is a small error on a transient
  // rather than an audible change in a sustaining sound.
  void setToneAndNoise(ushort ch, ushort divisor, ushort noisefreq, ushort ampl,
                       bool keepNoise = false) {
    uint8_t chip = ch % 3;
    uint8_t sub  = ch / 3;
    unsigned char *r = regs[chip];

    r[TONEALOW  + (sub<<1)] = (divisor & 0xFF);
    r[TONEAHIGH + (sub<<1)] = (divisor >> 8);
    if (!keepNoise) r[NOISEGEN] = noisefreq;
    r[TONEAAMPL + sub] = ampl;

    ushort mask = (8+1) << sub;
    ushort bits = (noisefreq < 16 ? 8 : 0) + (divisor > 0 ? 1 : 0);
    r[MIXER] = (r[MIXER] | mask) ^ (bits << sub);
  }

  // Pitch only, for a channel something else owns the amplitude of. Also
  // re-asserts tone and noise OFF in the CACHE every tick. Doing it with a
  // raw writeReg left the cache still saying "tone enabled", so any
  // invalidate() -- which every parameter change causes -- rewrote the
  // mixer from the cache and the square came back underneath.
  void setTonePitchOnly(ushort ch, ushort divisor) {
    uint8_t chip = ch % 3, sub = ch / 3;
    unsigned char *r = regs[chip];
    r[TONEALOW  + (sub << 1)] = divisor & 0xFF;
    r[TONEAHIGH + (sub << 1)] = (divisor >> 8) & 0x0F;
    r[MIXER] |= (uint8_t)((1u << sub) | (8u << sub));
  }

  void setEnvelope(ushort ch, ushort divisor, ushort shape) {
    uint8_t chip = ch % 3;
    unsigned char *r = regs[chip];
    r[ENVLOW]  = (divisor & 0xFF);
    r[ENVHIGH] = (divisor >> 8);
    r[ENVSHAPE] = shape;

    // Writing R13 is what RESTARTS the envelope, and the register cache
    // suppresses a write when the value has not changed. Every drum in the
    // kit uses shape 9, so a drum landing on a chip whose envelope is still
    // set to 9 by another drum got no restart at all -- it played into an
    // envelope that had already decayed to nothing, and was silent. Push the
    // period through the cache, then rewrite the shape unconditionally.
    update(chip);
    writeReg(chip, ENVSHAPE, (unsigned char)shape);
    lastregs[chip][ENVSHAPE] = (unsigned char)shape;
  }

  void setPercOff(ushort ch) {
    uint8_t chip = ch % 3;
    uint8_t sub  = ch / 3;
    unsigned char *r = regs[chip];

    ushort mask = (8+1) << sub;
    r[MIXER] |= mask;
    r[TONEAAMPL + sub] = 0;

    // The envelope generator is per-CHIP and shared by all three channels.
    // Zeroing it unconditionally cut off any other drum still sounding on
    // this chip, which is why drums choked each other. Only reset it once
    // no other channel here is still driven by it (M bit, 0x10).
    bool envInUse = false;
    for (uint8_t s2 = 0; s2 < 3; s2++) {
      if (s2 != sub && (r[TONEAAMPL + s2] & 0x10)) { envInUse = true; break; }
    }
    if (!envInUse && r[ENVSHAPE] != 0) {
      r[ENVSHAPE] = 0;
      update(chip); // Force flush
    }
  }

  // setOff() was an exact duplicate of setPercOff() in the original.
  void setOff(ushort ch) {
    setPercOff(ch);
  }

  // --- Buzzy bass -----------------------------------------------------
  // The AY's envelope generator is one-per-chip, shared by all three of
  // that chip's channels, and a channel's volume is driven by it whenever
  // bit 4 (0x10, the "M" bit) of its amplitude register is set -- in which
  // case the lower 4 (fixed-level) bits are ignored by the chip. ratio
  // scales the channel's tone divisor to get the envelope-period divisor;
  // there's no clean closed-form for "in tune", so this is meant to be
  // tuned by ear via the ratio control rather than computed exactly.
  void applyBuzzGate(uint8_t chip, uint8_t sub, bool pure) {
    // The tone gate stays open by default, so the square gates the envelope
    // and the output is the product of the two. Closed, only the envelope
    // reaches the output: the hardware sawtooth or triangle on its own.
    unsigned char *r = regs[chip];
    if (pure) r[MIXER] |= (uint8_t)(1u << sub);
    else      r[MIXER] &= (uint8_t)~(1u << sub);
  }

  void applyBuzz(uint8_t chip, uint8_t sub, ushort toneDivisor, uint8_t ratio,
                 uint8_t shape, int8_t detune) {
    unsigned char *r = regs[chip];
    // The envelope's full cycle is clock/(256*EP) while the tone is
    // clock/(16*TP), so the envelope only oscillates AT the note when
    // EP = TP/16. Multiplying the tone divisor directly, as this used to,
    // put it four octaves below the note -- a slow amplitude pulse rather
    // than a waveform. Divided down, the looping shapes become what they
    // actually are: a hardware sawtooth or triangle at the played pitch.
    // Ratio now means octaves below that: 1 unison, 2 an octave, 4 two.
    int32_t envDivisor = (((int32_t)toneDivisor * ratio) + 8) / 16 + detune;
    if (envDivisor < 1) envDivisor = 1;
    if (envDivisor > 65535) envDivisor = 65535;
    r[ENVLOW]  = envDivisor & 0xFF;
    r[ENVHIGH] = envDivisor >> 8;
    r[ENVSHAPE] = shape;
    r[TONEAAMPL + sub] = 0x10; // M=1: volume follows the envelope generator
  }

  // Forces the next update() to rewrite every register. Needed after the
  // Warp Zone writes straight to the chip behind the cache's back: without
  // this the cache still believes the hardware matches regs[] and would
  // never correct the glitched values.
  void invalidate() {
    for (uint8_t c = 0; c < 3; c++) {
      for (uint8_t i = 0; i < 16; i++) lastregs[c][i] = ~regs[c][i];
    }
  }

  void clearBuzz(uint8_t chip, uint8_t sub) {
    // Just drop the envelope-mode bit; the very next normal tone/amplitude
    // write for this voice (next 100Hz tick, at most 10ms away) restores
    // the correct fixed-level volume.
    regs[chip][TONEAAMPL + sub] &= ~0x10;
  }
};

static PSGRegs psg;

// Voice generation ---------------------------------------

static const ushort
  MIDI_MIN = 24,
  MIDI_MAX = 96,
  N_NOTES = (MIDI_MAX+1-MIDI_MIN);
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
void loop() {
  midiEventPacket_t rx;

  pollSerialControl(); // BUZZ/VIB parameter commands over USB-CDC serial

#ifdef USBMIDI
  rx = MidiUSB.read();

#ifdef DEBUG
  //MIDI debugging
  if (rx.header != 0) {
    Serial.print("Received USB: ");
    Serial.print(rx.header, HEX);
    Serial.print("-");
    Serial.print(rx.byte1, HEX);
    Serial.print("-");
    Serial.print(rx.byte2, HEX);
    Serial.print("-");
    Serial.println(rx.byte3, HEX);
  }
#endif

  handleMidiMessage(rx);
#endif

#ifdef SERIALMIDI
  //Check for serial MIDI messages
  //MIDI.read();
  while (MIDI.read()) {
    // Create midiEventPacket_t
    rx = 
      {
        byte(MIDI.getType() >>4), 
        byte(MIDI.getType() | ((MIDI.getChannel()-1) & 0x0f)), /* getChannel() returns values from 1 to 16 */
        MIDI.getData1(), 
        MIDI.getData2()
      };

#ifdef DEBUG
    //MIDI debugging
    if (rx.header != 0) {
      Serial.print("Received MIDI: ");
      Serial.print(rx.header, HEX);
      Serial.print("-");
      Serial.print(rx.byte1, HEX);
      Serial.print("-");
      Serial.print(rx.byte2, HEX);
      Serial.print("-");
      Serial.println(rx.byte3, HEX);
    }
#endif

    handleMidiMessage(rx);
  }
#endif

  unsigned long now = millis();
  // Clock Warp drags the MCU's own tick along with the chip clock. Without
  // this only half of each sound moved: tone periods, noise colour and the
  // hardware envelope are chip-side and slow with the clock, but amplitude
  // decay, drum length, rolls and every LFO are counted here in milliseconds
  // and carried on regardless. A drum is mostly the MCU half, which is why
  // the effect barely showed on the kit. Scaling the tick makes it genuine
  // vari-speed: at the deepest sag everything runs near a third speed.
  uint8_t tickMs = 10;
  if (params[P_WARP_MODE] == 10) {
    uint16_t div = OCR1AL ? OCR1AL : DIVISOR;
    uint16_t t = (uint16_t)((10u * div + (DIVISOR / 2)) / DIVISOR);
    if (t < 3) t = 3;
    if (t > 40) t = 40;
    tickMs = (uint8_t)t;
  }
  if ((now - lastUpdate) >= tickMs) {
    update100Hz();
    lastUpdate += tickMs; // was += 5 against a >10ms check, causing the
                          // envelope/perc update rate to drift ~2x fast
                          // whenever the loop fell behind and had to catch up
  }

  // Warp Zone runs far faster than the 100Hz voice tick -- up to ~4kHz --
  // so it gets its own micros() timer. Unsigned subtraction handles the
  // ~70 minute micros() rollover correctly.
  if (params[P_WARP_MODE] != 0 || params[P_MIX_NOISE] < 15
      || params[P_CLOCK_ENABLE]) {
    unsigned long nowUs = micros();

    // The noise gate keeps its own fixed 4kHz clock: tying it to the warp
    // rate would turn a slow warp setting into audible noise chopping.
    if (params[P_MIX_NOISE] < 15 &&
        (unsigned long)(nowUs - lastNoiseUs) >= NOISE_GATE_US) {
      lastNoiseUs = nowUs;
      noiseGateTick();
    }

    // Clock Warp is not a mode, so the tick has to run when one is selected
    // or when the clock is enabled, or it would only work in company.
    if ((params[P_WARP_MODE] != 0 || params[P_CLOCK_ENABLE]) &&
        (unsigned long)(nowUs - lastWarpUs) >= warpIntervalUs) {
      lastWarpUs = nowUs;
      warpTick();
    }
  }

  psg.updateAll();

}

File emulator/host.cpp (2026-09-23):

// Host for the 8b8 emulator.
//
// Includes the real firmware as a single translation unit and drives it the
// way the Leonardo does: call setup() once, then call loop() repeatedly
// while time advances, and let the three emulated chips turn the register
// writes into audio. The firmware source is unmodified apart from one
// four-line AY_EMULATOR seam in writeReg().
//
// Built two ways from this same file:
//   build-native.sh  g++, renders a WAV, used by the tests
//   build-wasm.sh    emcc, exported to JavaScript for the web page
#include <stdint.h>
#include <string>
#include <vector>
#include <cmath>

#include "arduino_shim.h"
#include "ay8910.h"
#include "MIDIUSB.h"

// ---- storage for everything the shim declares ------------------------------
uint8_t  emuPins[32];
uint64_t emuMicros = 0;
uint8_t  TCCR1A = 0, TCCR1B = 0, TCCR1C = 0, TIMSK0 = 0, TIMSK1 = 0, SREG = 0;
uint16_t OCR1A = 0, TCNT1 = 0;
uint8_t  OCR1AH = 0, OCR1AL = 0;
uint8_t  emuEeprom[1024];
EEPROMClass EEPROM;
EmuSerial Serial;
EmuSerial Serial1;
MidiUSB_  MidiUSB;

// ---- the three chips -------------------------------------------------------
static AY8910 chips[3];

void emuWriteReg(uint8_t chip, unsigned char reg, unsigned char db) {
  if (chip < 3) chips[chip].write(reg, db);
}

// The firmware is one translation unit, exactly as the Arduino IDE builds it.
#define AY_EMULATOR 1
extern "C" void emu_wave_tick();
#include "../8b8_firmware.ino"

// ---------------------------------------------------------------------------
// Audio
// ---------------------------------------------------------------------------
// The chip model steps at clock/8 (see ay8910.h for why). The firmware
// programs Timer1 for a 1MHz master clock, so that is 125000 steps a
// second, box-filtered down to whatever rate the host asks for.
// The firmware generates the AY clock on Timer1, so the chips run at
// 16MHz / (2 * (1 + OCR1A)) -- 1MHz at the default divisor of 7. Reading it
// back each buffer is what lets Clock Warp work here: the emulator used a
// fixed 1MHz and would simply have ignored the whole effect.
static double chipClockHz() {
  const double d = (double)OCR1AL;
  return 16000000.0 / (2.0 * (1.0 + (d < 1.0 ? 1.0 : d)));
}

// Real boards AC-couple the chip output. Without modelling that, the steady
// DC level a muted channel puts out shows up as offset in the render.
static double  dcPrev = 0.0, dcOut = 0.0;
// ---------------------------------------------------------------------------
// Step sequencer clock
// ---------------------------------------------------------------------------
// Timing lives here rather than in JavaScript because setTimeout is at the
// mercy of the main thread, and on this page the audio callback IS on the
// main thread. Counting samples inside the render makes the beat exact: a
// step lands on the sample it should, no matter what the browser is doing.
#define SEQ_MAX_ROWS 32
#define SEQ_MAX_STEPS 64
// A length per cell rather than a bit per step: 0 is empty, otherwise how
// many steps the note is held for. A bitmask could not express that, and it
// capped the pattern at the 16 bits it happened to have.
static uint8_t  seqCell[SEQ_MAX_ROWS][SEQ_MAX_STEPS];
static uint8_t  seqNote[SEQ_MAX_ROWS];
static uint8_t  seqChan[SEQ_MAX_ROWS];     // 9 = percussion, else melodic
static double   seqGateLeft[SEQ_MAX_ROWS]; // samples until note-off, 0 = idle
static uint8_t  seqGateNote[SEQ_MAX_ROWS];
static int      seqRows = 0, seqSteps = 16, seqCurStep = 0;
static bool     seqRunning = false;
static double   seqSamplesPerStep = 0.0, seqAcc = 0.0;
// Swing, 0 to 1. Steps are sixteenths, so a swung pair is one long step and
// one short: 1/3 gives the 2:1 triplet feel a jazz ride sits on. The pair
// still totals two steps, so the tempo does not change.
static double   seqSwing = 0.0;

static double seqStepLen(int step) {
  if (seqSwing <= 0.0) return seqSamplesPerStep;
  return seqSamplesPerStep * ((step & 1) ? (1.0 - seqSwing) : (1.0 + seqSwing));
}

static double  sampleRate   = 44100.0;
static double  stepCarry    = 0.0;
static double  loopAccUs    = 0.0;
static double  waveAccUs    = 0.0;

// ---------------------------------------------------------------------------
// MIDI file playback
// ---------------------------------------------------------------------------
// Events are timestamped in seconds and fired from the render loop, not from
// a timer. The audio callback runs on the page's main thread, so a JS timer
// shares it: on a dense file the notes arrived in late bursts behind each
// buffer render. Here the clock is the sample count and cannot drift.
struct MidiEv { double t; uint8_t st, d1, d2; };

// Controller 123 is All Notes Off. Sent on both the melodic and percussion
// channels when playback stops or loops, so a note held across the join is
// not left sounding.
static void midiPanic() {
  MidiUSB.push(midiEventPacket_t{0x0B, 0xB0, 123, 0});
  MidiUSB.push(midiEventPacket_t{0x0B, 0xB9, 123, 0});
}
static std::vector<MidiEv> midiEvs;
static size_t  midiIdx     = 0;
static double  midiClockS  = 0.0;
static double  midiSpeedX  = 1.0;
static double  midiDurS    = 0.0;
static bool    midiRunning = false;
static bool    midiLoopOn  = false;
static bool    started      = false;

extern "C" {

void emu_init(double rate) {
  sampleRate = rate;
  stepCarry = 0.0;
  loopAccUs = 0.0;
  waveAccUs = 0.0;
  dcPrev = dcOut = 0.0;
  emuMicros = 0;
  memset(emuEeprom, 0xFF, sizeof emuEeprom);
  for (int i = 0; i < 3; i++) chips[i].reset();
  midiEvs.clear(); midiIdx = 0; midiClockS = 0.0; midiRunning = false;
  seqRunning = false; seqRows = 0; seqCurStep = 0; seqAcc = 0.0;
  memset(seqCell, 0, sizeof seqCell);
  memset(seqChan, 9, sizeof seqChan);
  memset(seqGateLeft, 0, sizeof seqGateLeft);
  setup();
  started = true;
}
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

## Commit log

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2026-09-18 Add generated parameter bank, effects engine and Warp Zone
    Bug fixes to the V2.2 baseline:
    - setPercOff() read the mixer register from the wrong chip (chip A branch
    read regs_C, chip C branch read regs_A), corrupting mixer state
    - update100Hz() advanced its timer 5ms against a 10ms check, so envelope
    and percussion timing ran roughly 2x fast whenever the loop fell behind
    - an unconditional Serial.print in startFX() ran even when Serial.begin()
    was never called
    Performance and size:
    - register writes use direct AVR port I/O instead of digitalWrite()
    - writeReg_A/B/C, regs_A/B/C, update_A/B/C and the triplicated per-channel
    if-chains collapse to one chip-indexed implementation (chip =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
    [8b8_firmware.ino]
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2026-09-18 Parameter bank, effects engine, Warp Zone, Auto FX and digidrums
    Confirmed working on hardware.
    Fixes to the V2.2 baseline:
    - setPercOff() read the mixer register from the wrong chip
    - update100Hz() advanced its timer 5ms against a 10ms check, running
    envelope and percussion timing ~2x fast when the loop fell behind
    - an unconditional Serial.print in startFX() ran with Serial uninitialised
    - All Notes Off called resetFunc(), rebooting the MCU and dropping USB
    mid-session; replaced with softReset(), which silences voices and
    re-inits the chips without taking USB down
    - direct AVR port I/O instead of digitalWrite() for register writes
    - per-chip code collapsed to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
    [8b8_firmware.ino]
2026-09-18 Warp motion modes, drum FX, panel sections and themes, temperaments, master mixer
    Warp Zone:
    - four modes that move on their own: Tape Stop, Siren, Crush, Ring
    - Motion sweeps warp Rate hands-free, since the movement between
    settings is more interesting than any fixed setting
    Drum FX (drums are the only envelope-driven voices, so these reach
    things the tone effects cannot):
    - Roll re-strikes the envelope mid-hit, flam through buzz roll
    - Flam fires each hit a second time; cannot recurse
    - Reverse runs the envelope upward so hits swell then cut
    - Chaos varies pitch, noise colour and length on every strike
    Panel:
    - organised by what a control touches: Tone Voices, Drum Voices, and
    Warp Z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
    [8b8_firmware.ino]
2026-09-18 MIDI CC control of every parameter, plus a paged section nav
    Every parameter answers to a CC, defaulting to CC70 upward -- the sound
    controller / undefined range, which avoids mod wheel, volume, sustain,
    the bank-select LSBs and the channel mode messages already handled.
    Bindings are learnable from the panel and persist in EEPROM alongside
    the parameters, and an incoming CC echoes the same V: line a panel edit
    produces so the on-screen control follows the knob.
    Panel sections are now tabs rather than one long scroll, with an All
    view, remembered per browser.
    Also fixes handleLine() living inside the serial transport block, which
    left the emulator page calling a function that did not exist: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
    [8b8_firmware.ino, host.cpp]
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2026-09-18 Fix Warp Motion sweep rate; add settings menu and better intro text
    Motion used an 8-bit phase accumulator, which wrapped in a fraction of a
    second: at the useful settings it wobbled the warp rate 4-10 times a
    second, which averages out and sounds like nothing is happening. A
    16-bit accumulator with a scaled step gives sweeps from about half a
    second to half a minute, which is what a hand on a fader looks like.
    Theme and text size move behind a Settings button, joined by a Detail
    setting whose Compact mode hides per-control help and section blurbs.
    The intro text now says what the tool is, written separately for the
    hardware panel and the emulator.
    [8b8_firmware.ino]
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2026-09-18 Make the emulator sequencer sample-accurate
    setTimeout is clamped and delayed whenever the main thread is busy, and
    on the emulator page the audio callback runs on that thread, so every
    render nudged the next step late. The step clock now counts samples
    inside the audio render: worst deviation 0.011ms, one sample of drift
    over four seconds.
    loop() ran once per sample, 44100 times per second of audio for a
    firmware whose fastest timer is 4kHz; now throttled to about 8kHz. The
    playhead caches its cells instead of re-querying 128 elements per step.
    The hardware panel keeps the timer engine, since notes reach the unit
    over serial and there is no audio clock to align to.
    [host.cpp]
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2026-09-19 Fix drums silently dropped when a chip's envelope was already busy
    Writing R13 is what restarts the AY envelope, but setEnvelope() wrote
    through the register cache, which skips a write when the value has not
    changed. Every drum in the kit uses shape 9, so a drum landing on a chip
    whose envelope was still set to 9 by another sounding drum got no
    restart and played into an envelope that had already decayed to nothing.
    Breakbeat step 14, the only step where two drums fire while all three
    chips are busy, measured 0.0008 rms against 0.026-0.083 for every other
    hit. It is now 0.1377, and the snare+hat steps roughly doubled as well.
    All five shipped patterns play every hit.
    [8b8_firmware.ino]
2026-09-19 Space Drum Roll and Retrigger by ratio instead of by Hz
    Rhythm is heard in ratios, so a linear Hz control put a doubling between
    the first two fader positions and almost nothing across the top half.
    The rate now follows an exponential curve from 1.5Hz to 50Hz, emitted
    from generate.py as a lookup table: median step 1.07x rather than 2x at
    the bottom, monotonic throughout.
    Above position 44 the steps repeat because a 100Hz tick cannot resolve
    between 33 and 50Hz, but the resolution now sits where it is audible.
    Buzz Roll, Broken Machine and Machine Gun are re-pointed to the values
    that give the rates they had before.
    [8b8_firmware.ino]
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2026-09-19 Add a note sequencer and variable pattern length
    Twelve semitone rows below the drum grid, polyphonic, with an octave
    control. Melodic rows are not one-shots like drums: each row carries its
    channel and gets a note-off gated at 60 per cent of a step so repeated
    notes articulate, and stopping releases anything still held.
    Pattern length is selectable from 1 to 16 and drives both grids from the
    same clock. Steps past the length are dimmed rather than cleared, so
    shortening and lengthening a pattern does not lose what was drawn.
    [host.cpp]
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2026-09-19 Make Warp depth a consistent magnitude in every mode
    Depth was read differently in each mode and in some was not a magnitude
    at all: Sync Buzz never read it, Stutter used it as a raw bit pattern so
    32 was gentler than 31, Scramble had four values across sixty-three
    positions, and Crush masked no bits below depth 9.
    Every mode now scales monotonically over the full range. Sync Buzz sets
    how many channels the envelope drives, Stutter how many sources are
    gated, Scramble both how many registers are hit and how far each value
    may move, and Crush the peak coarseness of the sweep.
    Tape Stop and Siren take their multiplier from an exponential table, so
    the pitch drop is linear in semitones rather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
    [8b8_firmware.ino]
2026-09-19 Fix ADSR sustain discontinuity and make segments times, not rates
    Sustain was a fraction of the STARTING amplitude, which was ~968 with
    attack 1 and ~256 with attack 2, so nudging attack past 1 collapsed the
    sustain level to a quarter. It is now a fraction of the peak the note
    reaches.
    The decay case set the sustain level and then subtracted one more decay
    step anyway, so the held level was low by that step and depended on the
    Decay setting.
    Attack, decay and release were per-tick rates: time was reciprocal, and
    higher meant shorter. They are now times, exponentially spaced from 10ms
    to 4s, taken from a table in 1/16ths with a carry accumulator, since an
    integer rate rounds a four second s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
    [8b8_firmware.ino]
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2026-09-20 Fix the master mixer taper, and the emulator's amplitude DAC
    The mixer multiplied the amplitude register, which is a logarithmic
    index, so it scaled a dB value -- and it truncated, muting a decaying
    note several fader positions before a full one. It now subtracts an
    attenuation from a table: a true dB cut, identical for loud and quiet
    notes, on a curve whose top half covers about 9dB. The Drums mixer gets
    the same treatment.
    The emulator's DAC was a flat 3dB ladder that jumped 6dB between the top
    two entries, so the first notch off full lost twice what it should have
    and every level control read steeper than on hardware. Replaced with the
    chip's measured table, which runs about 1.4dB per st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
    [8b8_firmware.ino]
2026-09-21 Make drum Tune and Bend reach the noise-only drums
    Both worked on the tone divisor, and half the kit has no tone: snare,
    every hat and cymbal, tambourine and side stick are pure noise. Tune
    reached 12 of 25 drums and Bend 9; on the rest they did nothing at all.
    For a noise drum the noise period is the pitch. Tune shifts it rather
    than scaling it, because the range is sixteen integers and the hats
    already sit at 0, where a ratio moves them one step and the chip cannot
    tell 0 from 1. Bend darkens the noise across the decay, the same gesture
    as a kick's pitch drop, and can introduce a sweep on a drum that had
    none rather than only scaling an existing one.
    [8b8_firmware.ino]
2026-09-21 Add Env Crush, Unison and Clock Warp
    Env Crush quantises the envelope period rather than the tone, so decays
    and buzz tones stair-step while the pitch holds.
    Unison doubles each melodic note on a second voice, detuned by shifting
    the tone divisor rather than transposing, so the beat is wider low down
    and narrower high up. It only takes a genuinely spare voice, and both
    release together.
    Clock Warp wobbles OCR1A, the timer generating the AY master clock, so
    it sits upstream of all three chips: pitch, noise colour, envelope rates
    and drum decays move together. Measured 667kHz to 1.6MHz, capped below
    the datasheet's 2MHz. The emulator now reads the clock back rather than
    assuming a fixed 1MHz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
    [8b8_firmware.ino, host.cpp]
2026-09-21 Make Clock Warp carry the MCU's tick, not just the chip clock
    Only half of each sound moved. Tone periods, noise colour and the
    hardware envelope are chip-side and slowed with the clock, but amplitude
    decay, drum length, rolls, flams and every LFO are counted on the 100Hz
    tick in milliseconds and carried on regardless. A drum is mostly that
    second half, which is why the effect barely showed on the kit.
    The tick now scales with the clock divisor. Measured across eight kicks:
    300-310ms steady with the mode off, 220-438ms with it on. At the fastest
    clock the tick reaches 166Hz, 1.67x the usual update load.
    [8b8_firmware.ino]
2026-09-21 Give Env Crush a range that actually bites
    The bit range was borrowed from the tone crush without checking the
    numbers. Tone periods run 50 to 500, where masking six bits is a large
    relative change; envelope periods run into the thousands, where the same
    six bits moves them under two per cent. The mode was inaudible.
    It now reaches twelve bits, where the period snaps somewhere genuinely
    different, and the sweep starts from half depth rather than zero so it
    is always doing something rather than passing through untouched for half
    its cycle. At full depth the period can reach 1, about 4kHz, and the
    decay becomes a buzz.
    [8b8_firmware.ino]
2026-09-21 Measure free RAM instead of inferring it
    setup() paints the gap between the globals and the stack with a known
    byte, so counting how many survive gives the closest the stack has ever
    come to the globals -- the figure that matters, rather than the
    compiler's static one. Reported on DIAG as free-now and lowest-ever, and
    shown in the panel log with a warning under 256 bytes.
    A stack overflow on AVR does not fault; it quietly corrupts globals and
    surfaces as inexplicable misbehaviour, which is exactly the failure this
    makes visible. The emulator reports nothing, since it runs on the host
    stack.
    [8b8_firmware.ino]
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2026-09-21 Fix Buzzy Bass to run at audio rate; add a wavetable voice
    The envelope's cycle is clock/(256*EP) and the tone is clock/(16*TP), so
    the envelope only oscillates at the note when EP = TP/16. applyBuzz
    multiplied the tone divisor instead, putting it four octaves below --
    a slow amplitude pulse rather than a waveform. Divided down it lands
    within 7 cents of the note and the looping shapes are what they always
    were: a hardware sawtooth or triangle. Ratio now means octaves below,
    and the buzz presets are re-pointed to unison.
    The wavetable voice takes a channel, switches its tone and noise off so
    the amplitude register is a bare 4-bit DAC, and writes a waveform into
    it from Timer3 at 16kHz -- th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
    [8b8_firmware.ino, host.cpp]
2026-09-21 Fix wavetable voice latency and amplitude contention
    applyWavetable() only ran from the 100Hz tick, so a wavetable note
    started up to 10ms after the key, varying with where it fell in the
    cycle. It now runs as the note starts: measured onset matches a plain
    square voice.
    The voice tick was also writing that channel's amplitude from its ADSR
    while the ISR wrote it at 16kHz, putting a step in the waveform a
    hundred times a second. The ADSR still runs, since it ends the note, but
    only the pitch is written for a channel the wavetable owns.
    [8b8_firmware.ino]
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2026-09-21 Stop drums truncating each other when every chip is busy
    One envelope generator per chip, shared by three channels. The allocator
    prefers a chip with an idle envelope, but when all three are ringing the
    next drum overwrote the period and restarted it, cutting the drum that
    was there. Measured: one hat dropped a crash's period from 2500 to 300.
    Hats show it worst because they are the most frequent hit and carry the
    shortest period in the kit, so they do the most damage when they land; a
    kick onto a ringing hat lengthens it instead and goes unnoticed.
    A drum with no free chip now decays on its software amplitude, the path
    the drum level control already uses, and leaves the shared envelope
    al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
    [8b8_firmware.ino]
2026-09-21 Make the drum rows assignable to any drum in the kit
    The sequencer exposed eight of the twenty-five drums. Each row is now a
    picker onto the whole kit, rather than a second page of rows: a pattern
    using drums from two pages could never be seen at once, and the working
    set is small enough that choosing it beats paging through it.
    Patterns stay with the row, so repointing one plays the same rhythm on a
    different drum. Assignments persist per browser, and presets still
    address rows by their default name so they land correctly after a row
    has been changed.
    [8b8_firmware.ino]
2026-09-21 Add clave and jazz patterns, and a swing control
    Swing runs 0 to 66 per cent in the sample-accurate clock: a swung pair
    is one long step and one short, the pair still totalling two steps so
    the tempo is unchanged. A third is the 2:1 triplet feel.
    Clave 3:2, Clave 2:3 and Jazz Ride are two bars each, since both figures
    are two-bar. Presets can now repoint rows onto the drums they need, the
    rows being a working set rather than a fixed kit, and a preset reaching
    past step 15 loads from the start and grows the loop rather than landing
    half on one page and half on another.
    [host.cpp]
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2026-09-21 Give Clock Warp the range and hold of a clock-halving switch
    Depth swung five divisor steps, bottoming at 615kHz. A YM2149 with SEL
    low runs at 500kHz, so the effect could not reach the sound a hardware
    halving switch makes. Depth now reaches thirteen steps, down to 381kHz.
    It also only swept: a sine visits its extreme for an instant, where a
    switch holds there. The slowest rate now holds the clock down instead of
    sweeping it, which is where the coarse, slow character comes from. Rate
    1 was an imperceptibly slow sweep before, so no parameter ranges change
    and saved banks are unaffected.
    [8b8_firmware.ino]
2026-09-21 Name the Warp controls for the selected mode
    Rate, Depth and Motion do different jobs in each of eleven modes and the
    panel named them for none of them, so nothing indicated that Clock
    Warp's hold sat at the bottom of Rate. Each mode now labels the three
    knobs for what they do there.
    Clock Warp's hold moves to Motion: zero sweeps, full holds the clock
    down, between mixes the two, so turning a control up gives more of the
    effect. Rate returns to meaning sweep speed.
    Parameter controls carry no id and Mode is a row of buttons rather than
    a select, so the labels are found by module and the mode read from the
    active button. Only the label's text node is rewritten, leaving the CC
    binding tag in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
    [8b8_firmware.ino]
2026-09-21 Make Clock Warp its own block, usable with any mode
    Clock Warp writes no chip register, only OCR1A, the timer generating the
    AY master clock, so nothing downstream can contend with it. As a mode it
    was mutually exclusive with the others for no reason.
    It moves out of the mode list into its own group with Enable, Drop,
    Sweep and Hold, and runs beside whichever mode is selected or alone with
    none. Three gates assumed a mode was selected before the warp timer ran
    at all, which is why it worked only in company.
    Four parameters added, so the layout version changes and saved banks
    reset.
    [8b8_firmware.ino]
2026-09-22 Make Clock Warp's Drop work across its whole range
    Drop did nothing below 8 and then jumped. The mapping rounded its first
    three positions to zero and gave the next four a swing of one, which the
    sweep's divide by 127 then truncated to zero everywhere except the two
    sine peaks, so those did nothing either.
    Drop 1 now gives one divisor step, the smallest the hardware has, and
    the range spreads evenly to thirteen. OCR1A is an integer, so that floor
    of roughly 218 cents cannot be made finer without dithering the clock.
    [8b8_firmware.ino]
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2026-09-22 Add a Pure switch to Buzzy Bass
    The channel's tone gate stayed open while its amplitude followed the
    envelope, so the square gated the envelope and the output was the
    product of the two. That is a good default but there was no way to hear
    the envelope alone. Pure closes the gate, giving the hardware sawtooth
    or triangle by itself: measured, the peak rises by half and the
    triangle's zero crossings halve as the square's gating disappears.
    [8b8_firmware.ino]
2026-09-22 Add a SID Voice warp mode
    Hard square modulation of one voice's amplitude at the full warp rate.
    Ring already did this to every channel but rotates a chip per tick, so
    each sees the toggle only every sixth one: measured at 613Hz against
    1825Hz here, and it costs nine register writes a tick where this costs
    one. The higher rate is where the modulation stops sounding like tremolo
    and becomes an edge on the note.
    [8b8_firmware.ino]
2026-09-22 Add drawbars: harmonics of each note on further voices
    Summed squares at organ footages reshape the timbre rather than merely
    thickening it, which on a chip with no filter is the only route to a new
    tone colour. Two stops from the classic footages, each with its own level
    and its own voice. A stop never steals a voice: a harmonic is not worth
    a note, so it is skipped when none is spare.
    Releasing a note sweeps every voice carrying it rather than the lead and
    one twin, since a note can now claim three.
    [8b8_firmware.ino]
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2026-09-22 Add the cheat code and patch passwords
    Up up down down left right left right B A, on the keyboard or a gamepad,
    unlocks five patches kept out of the normal list and, on the emulator
    only, lifts the master clock's limits. The hardware panel never offers
    that: there is a real chip on the other end of the wire.
    Lifting the clamp alone changed nothing, since the clamp was not the
    limit -- Drop maxed at thirteen steps and landed exactly on it. Unlocked,
    Drop reaches the whole range the timer can produce.
    A password carries a patch alone by encoding only what differs from
    Init, which is what keeps it short enough to read aloud. Crockford
    base32, with a position-weighted check character that catc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
    [8b8_firmware.ino]
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2026-09-23 Add pitch bend, and key notes by channel as well as number
    Pitch bend was ignored. It is now per channel, which under MPE is per
    note, and every AY voice has its own tone period to receive it: a glide
    sent one voice per channel plays back as independent slides. RPN 0 sets
    the range; an MPE zone declaration implies the MPE default of 48 on
    every channel, since a member channel's range is not sent.
    The bend is applied after the temperament as a smooth shift. Moving the
    note number first retuned a bent C as a C sharp, which in an unequal
    temperament is not a semitone away, so a chord bent together changed
    shape. Whole semitones are an equal-tempered ratio between note table
    entries and the rem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
    [8b8_firmware.ino, host.cpp]
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2026-09-23 MPE input that works with a two-port controller
    Under MPE a channel is a note's bend lane, but the channel also picked
    the tone preset (chan % 4), so an MPE stream scattered one instrument
    across four envelopes, two with half-second attacks. MPE mode puts every
    channel on preset 0 and gives member channels the MPE bend range of 48,
    set by a zone declaration or MPE:1.
    All Notes Off reset the bend range to 2, and the MIDI file player sends
    it at every loop. It now centres the bends and keeps range and mode.
    In the emulator each (port, channel) gets its own lane. The minichord
    numbers chord voices and strings from channel 2 on separate ports;
    merged, they shared a channel, a bend and a note-o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
    [8b8_firmware.ino]
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2026-09-23 Add a septimal chord set, unlocked by BARBERSHOP
    A Septimal switch beside Barry, hidden until the password is entered,
    turns the matrix's seven chords into 7-limit counterparts: supermajor
    14:18:21, subminor 6:7:9, harmonic seventh 4:5:6:7, utonal, supermajor
    and subminor sevenths, and a utonal seventh in the augmented slot.
    A chord tone is a MIDI note, so it lands on a pitch of the temperament,
    which has no 9:7 third. The panel sends the firmware a table of cents
    per pitch class for the held chord and sounding notes retune in place,
    so flipping the switch moves only the tuning. The temperament is set
    aside while the table is on, since the ratios are measured from an
    equal-tempered root.
    B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
    [8b8_firmware.ino]
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

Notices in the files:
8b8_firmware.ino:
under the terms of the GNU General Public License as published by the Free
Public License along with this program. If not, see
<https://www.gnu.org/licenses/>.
